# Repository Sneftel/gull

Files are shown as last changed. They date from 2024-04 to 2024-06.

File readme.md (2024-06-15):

# Gull

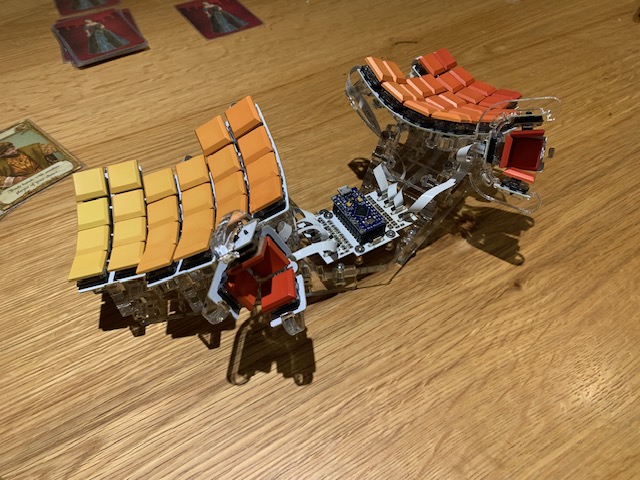
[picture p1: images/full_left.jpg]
Full-frame, three-quarters angle photo of a sweet-ass keyboard


**NOTE:** These images are from Gull V1. V2 is quite similar, but the thumb cluster attaches to the rib rather than being a part of it.

Gull is a dished ergonomic keyboard. It contains no 3D-printed parts and no hand-wired circuitry, and is designed for rapid constructibility rather than aesthetics. Keys are inserted into thin FR4 PCBs which are bent to the frame.

The raison d'etre of Gull is to be rapidly assembled, tweaked, and remade. The frame is fully parameterized, and changing a parameter generally only requires recutting one shape. PCBs can be reused after changing almost any parameters. The exposed ribbon cables make it potentially impractical for portable use.

The key layout is essentially 3x6 on each side. There are six additional keys per side, two in the bottom center of each side and four (relatively inaccessible) keys at the top corners of each side.

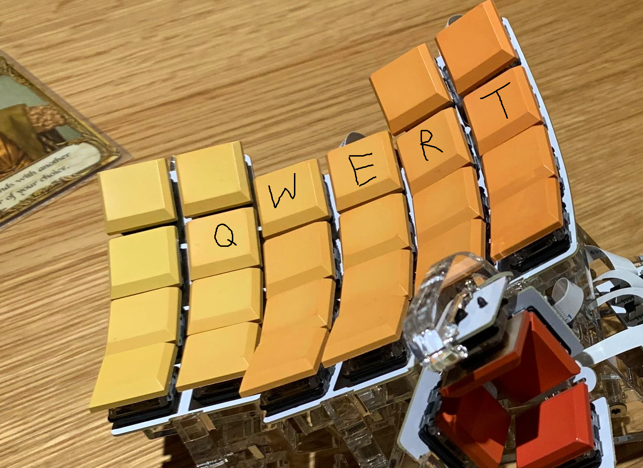
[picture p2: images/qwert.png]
Diagram of the alignment of the QWERTY layout with the key layout


PCB layout is in KiCad. Frame shapes are in OpenSCAD. The firmware is QMK; the fork is available at https://github.com/Sneftel/qmk_firmware/tree/gull , and will be PR'd back when I get some time to clean it up.

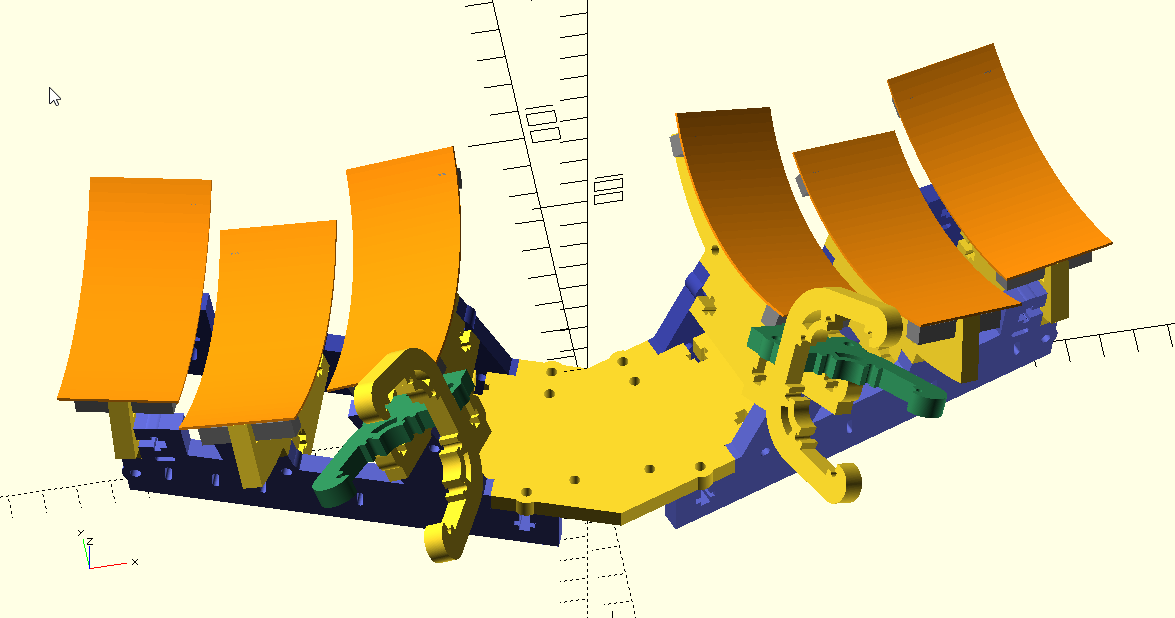
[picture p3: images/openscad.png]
Screenshot of editing the keyboard in OpenSCAD


## Tools

The frame for Gull must be cut from acrylic or similar using a laser cutter.

The PCBs have surface-mount components. A hotplate is the best tool for soldering these, but hand soldering is also possible. Hot air reflow can be used but be aware of temperature limits for the FFC connectors.

Good tweezers are useful for working with the FFC cables, particularly with SOWgull.

## Materials

I use six millimeter-thick acrylic for the frame. Eight millimeter will also work. Below six millimeters is not recommended. Plywood will likely also be acceptable, though I have not tested the most recent shapes with plywood.

The finger and thumb PCBs should be fabricated from 0.8mm-thick FR4. I have not tested other materials or thicknesses. The center PCB should be fabricated from thicker FR4 (I use standard 1.6mm-thick FR4).

## Parts

The following parts are required:

### Hardware 

* 38 14mm-long M3 bolts (not countersunk)
* 26 10mm-long M3 bolts (not countersunk)
* 56 M3 square nuts. I used 6mm width, 2mm thickness, but other sizes will also work.
* 4 4mm female-threaded hex spacers
* 2 20mm female-threaded hex spacers for each bending clamp (optional, discussed below)
* 4 M3 hex nuts

### Components

* 56 Kailh Choc V1 low-profile keyswitches
* 56 Choc V1 keycaps
* 56 0805 diodes
* 16 vertical FFC connectors, 10 pin, 0.5mm pitch. I used GCT FFC2A33 connectors. Other brands will likely work, but check that the land pattern is roughly equivalent. In particular, check that the upper pins are skewed right of the lower pins.
* 8 FFC ribbon cables in various lengths from 10cm to 25cm, 10pin, 0.5mm pitch. I used type B (opposite side contacts) because that gives more flexibility to orient them with the marked side hidden, but type A will also work.
* Pins and sockets for a Pro Micro MCU
* Pro Micro MCU (or pinout-compatible)

### Laser-cut pieces

* 6 ribs, 2 for each position
* 4 spines
* 2 thumb cluster necks
* 2 thumb cluster bodies
* 12 stabilizers
* 1 pelvis
* 2 bending clamps for each distinct rib radius (optional, discussed below)

### PCBs

* 6 fingerboards, in 0.8mm FR4
* 2 thumbboards, in 0.8mm FR4
* 1 centerboard, in 1.6mm FR4 or similar

## Customization

### Basic development

Most customization should be done through frame/params.scad. This file contains almost all parameters one might want to tweak, and documents which pieces are affected by which parameters. 

To visualize the keyboard as a whole, open frame/main.scad. This file should not be used to generate shapes for laser cutting.

### Dilation

The OpenSCAD files dilate some parts to account for the laser cutter's kerf. If your cutter's control software includes this as a feature, you should either disable it in the control software, or disable the dilation by setting the KERF parameter in params.scad to 0. Otherwise, cut a 10mm square, measure the average of its side lengths and subtract that from 10, and set KERF to that value. If the kerf is above 0.6 or so, you may have trouble getting things to fit firmly.

### Customizing the T-slots

For easy assembly, it's useful for the square nuts to firmly friction-fit into the T-slots. This requires a fairly tight tolerance. The "tnuttester.scad" file can be used to empirically determine the right parameters for this, given a particular laser cutter and material. See the comments in that file for how to use it.

### Customizing the bending clamp

If you have customized the rib radii, you will need to customize the bending clamp radius to match (the parameter BEND_RADIUS in clamp.scad), and you will need to fabricate separate clamp shapes for each distinct rib radius. 

## Fabrication

### PCBs

The fingerboards and centerboard may be panelized or printed as-is. To build Gerber files which should be acceptable at most fabs (I use Elecrow), run makeall.bat or "make" in the board directory.

The thumbboard has delicately narrow areas and should be carefully panelized for fabrication. I use KiKit for this, with "panelize.json" containing the necessary presets. The auto-built Gerbers are panelized in this way. Make sure to mention the need for V-cuts to the PCB fabricator. Mousebites would also work.

The center FFC connector on the centerboard, just below the MCU, is for future expansion and does not need to be populated.

### Laser-cut shapes

Execute "make svg" or (on Windows) "makeall.bat svg" to generate SVG shapes for all laser-cut pieces. DXF and PDF outputs are also supported.

I use Deepnest.io to nest the pieces for printing. Consider manually nesting the stabilizers and printing them separately.

The OpenSCAD files dilate some parts to account for laser-cut kerf. See the discussion of kerf in the "customization" section.

## Assembly

Follow the following steps for assembly:

### Solder the PCBs

The thumbboards should remain panelized until after both SM and TH components are soldered. 

Solder only one connector per thumbboard: J1 on one, J2 on the other. The thumb cluster switches will be on the opposite side from the connector.

The FFC connectors have pin 1 indicators that are subtle at best. Make sure to solder them consistently; the connections will work when reversed if the column pin mapping is reversed.

### Assemble the frame

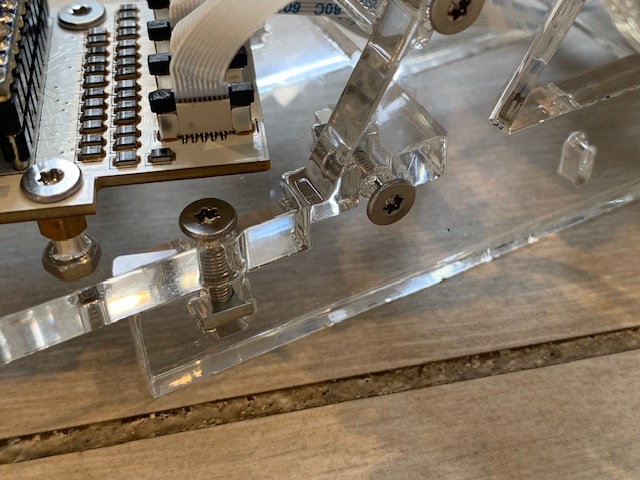
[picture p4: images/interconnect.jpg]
Closeup of the frame interconnects


It's marginally easier to do this before attaching the thumb and finger PCBs. First attach the spines to the pelvis, then the ribs to the spine. (You will use only the 14mm bolts for these.)

Ideally, the square nuts can be press-fit into the T-slots and will stay there for assembly. If a fit is too loose or tight, try a different nut, or try rotating the nut. A drop of glue, or a piece of tape, can also be used to keep things in position.

### Assemble the bending clamp

The shapes include a clamp for use when mounting the fingerboards to the ribs. You can insert each fingerboard into the clamp (keys towards the clamp) and bend and hold it in place with one hand. This makes it easier to bolt it down. 

However, this clamp requires 20mm spacers, which you otherwise wouldn't need, so you can keep your BOM down a bit by bending the fingerboards without one; this option is discussed below.

To assemble the clamp, insert a 10mm bolt in each hole and screw down to a 20mm spacer on the other side. Then put the other clamp on the other side of the spacers and bolt to the spacers with two more 10mm bolts.

### Mount fingerboards

If you have the bending clamp: Insert a fingerboard all the way into the back of the clamp (the FFC connector will be towards the back, and facing the curved surfaces of the clamp), place a stabilizer on the fingerboard (under the hooks at the end) and bend and hold it to the curve with your non-dominant hand.  Use your other hand to insert the bolts and screw them down, inserting a second stabilizer on the other side as you do so. Then tighten everything down and adjust the stabilizers.

If you don't have the bending clamp: It's easiest to mount the fingerboards with two people, one bending the board to the frame and one inserting the 10mm bolts. Failing that, bend in as well as possible and attach the center bolt but do not fully tighten it. Then insert a stabilizer on each side (it will not yet fit firmly). Continue to bend and attach the other two bolts, then tighten everything down and adjust the stabilizers.

### Mount thumbboards

Break off the frames. Fit square nuts into the thumb cluster bodies for later. 

The thumb cluster PCBs should have the connector facing away from the user; swap left and right if this is not the case. Carefully bend the row of three keys to insert into the body of the thumb cluster, with the PCB inserted from the same side as the T-slot is on. Go slow and make sure the PCB is slotting in correctly. The fit should be firm but there should be no need to force anything.

Then attach the necks. Both will slide in from the bottom. Bolt the necks in while checking for centered and square positioning. Then attach the thumb clusters to the rest of the frame.

### Mount centerboard

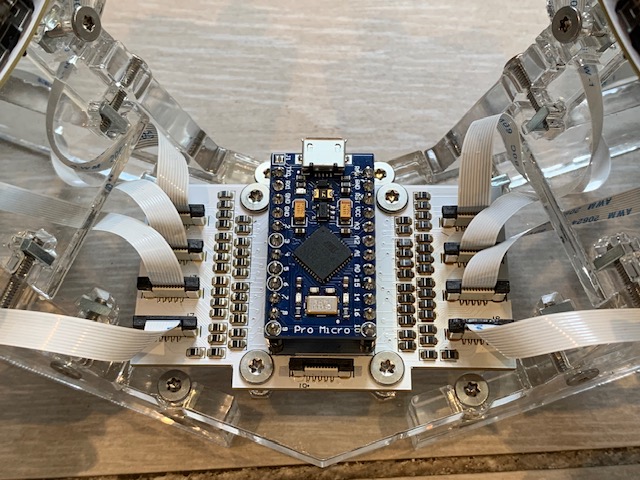
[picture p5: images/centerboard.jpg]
Closeup of the centerboard


Attach four 14mm bolts from the top of the centerboard and secure finger-tight with the 4mm spacers on the bottom. Insert the bolt shanks through the holes in the pelvis and secure with nuts.

### Attach cables and microcontroller.

Insert and secure FFC ribbon cables in the centerboard one by one, fishing them through the frame and inserting them into the fingerboards and thumbbboards. Take care they are oriented properly, and if desired reverse them so the printing is on a consistent side. The thumb cluster cables must be connected to the two side connectors closest to the user. The other cables are intended to be connected with the outermost fingerboards on the connectors further from the user, but row pins can be remapped to compensate if they are connected differently.

Finally, insert the microcontroller. (It's easiest to do this last, so there's more room to connect the cables.)

### Fix row/column mappings

There's a decent chance that the row/column mappings in info.json won't be correct, depending on which FFC cables you used and how you mounted the connectors. If you add 

## SOWGull

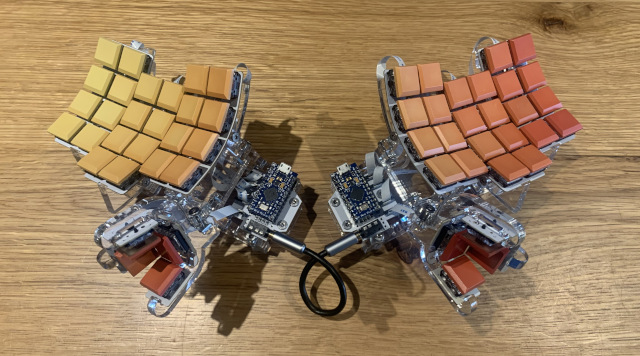
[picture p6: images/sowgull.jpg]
Gull, but split


SOWGull is a split variant of Gull, with a 3.5mm audio cable used to connect the halves.

Most of SOWGull is the same as a normal Gull, and it is easy to convert a Gull into a SOWGull (or vice versa). Only the centerboard and pelvis differ.

### Parts

The BOM has the following differences:

* PCBs: Two SOW boards instead of one centerboard.
* Laser-cut shapes: Two sowpelvis shapes instead of one pelvis shape.
* Hardware: Two additional 10mm-long M3 bolts, two additional 4mm hex spacers, and two additional hex nuts.
* Components: Two PJ-320A 3.5mm TRRS jacks; two Pro Micro boards instead of one; a TRS or TRRS cable for connection.

### Assembly

The SOW board is a reversible PCB. The microcontroller board should be mounted with the USB port facing away from the user, and as far away as possible from the user (with four through-holes towards the user left unused). The TRRS jack is mounted closer to the user.

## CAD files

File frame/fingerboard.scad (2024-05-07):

// Curved fingerboard PCB shape. Used only by main.scad.

include <util.scad>
include <params.scad>
include <pn.scad>

module TopComponent(radius, x, y, width, height, depth)
{
	EXTRA_HEIGHT = sqrt(pow(radius-FINGERBOARD_THICKNESS, 2) - pow(height/2, 2));
	translate([0,radius,x]) RotZ(angleFromLen(radius, y)) translate([0,-EXTRA_HEIGHT+depth/2,0])
        pn_pos() cube([height, depth, width], center=true);
}

module BottomComponent(radius, x, y, width, height, depth)
{
	translate([0,radius,x]) RotZ(angleFromLen(radius, y)) translate([0,-radius-depth/2,0])
        pn_pos() cube([height, depth, width], center=true);
}

module Components(radius)
{
	TopComponent(radius, -10, 30, 14, 14, 6);
	TopComponent(radius, 10, 30, 14, 14, 6);
	TopComponent(radius, -10, 10, 14, 14, 6);
	TopComponent(radius, 10, 10, 14, 14, 6);
	TopComponent(radius, -10, -10, 14, 14, 6);
	TopComponent(radius, 10, -10, 14, 14, 6);
	TopComponent(radius, -10, -30, 14, 14, 6);
	TopComponent(radius, 10, -30, 14, 14, 6);
	BottomComponent(radius, 0, 35, 10, 2, 5);

}

module FingerboardPCB(radius)
{
	EXTRA = 1;

	REAR_ANGLE = angleFromLen(radius, FINGERBOARD_REARWARD_EXTENT);
	FRONT_ANGLE = angleFromLen(radius, FINGERBOARD_FORWARD_EXTENT);

	color("#FF9209")
	linear_extrude(FINGERBOARD_PCB_WIDTH, center=true)
	translate([0,radius,0])
	RotZ(REAR_ANGLE/2-FRONT_ANGLE/2)
		pn_pos() CocktailSausage(minorRadius=radius-FINGERBOARD_THICKNESS, angle=REAR_ANGLE+FRONT_ANGLE, thickness=FINGERBOARD_THICKNESS);
		
	Components(radius);
}

pn_top() FingerboardPCB(80);

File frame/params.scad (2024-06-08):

// IMPORTANT PARAMETERS WHICH YOU MAY WELL WANT TO CUSTOMIZE
//
// These parameters are those you are most likely to want to customize because they relate directly to the positioning of the keys.
// Each parameter in this section is annotated with which parts it affects:
// S: spine
// RA, RB, RC: ribs (centermost to outermost)
// P: pelvis
// T: stabilizers
// N: TC neck
// B: TC body

// The nominal thickness of the sheet material. Parts will still mate and work properly if they vary from this width by up to THICKNESS_TOLERANCE. (S)
THICKNESS = 6; //0.1

// The kerf width of the cutter. Determine this by subtracting the measured width of a cut piece from the nominal width. If your laser cutter software supports kerf correction including clearout of reflex corners, you may want to set this to zero. (ALL)
KERF = 0.3;

// Whether certain inside corners with parts fitting into them should be cleared with dogbone fillets. Disabling this may prevent pieces from fitting together as cleanly, and increase the risk of cracking in T-slots.
CLEAR_INNER_CORNERS = true;

// The position of the join point between the inner ribs and the spine, in the plane of the spine (S)
RIB_A_POS = [-40,45];
// The angle in the plane of the spine by which the inner ribs are rolled away from the center (S)
RIB_A_ANGLE = 30;
// The distance by which the inner ribs are shifted backwards from having their lowest point centered between the spines (RA)
RIB_A_SHIFT = 0;
// The radius described by the fingerboards on the inner ribs (RA)
RIB_A_RADIUS = 80; //5
// The angle by which the fingerboards on the inner ribs are canted away from the user (RA)
RIB_A_PITCH = 10;

// The position of the join point between the second ribs and the spine, in the plane of the spine (S)
RIB_B_POS = [-82,25];
// The angle in the plane of the spine by which the second ribs are rolled away from the center (S)
RIB_B_ANGLE = 20;
// The distance by which the second ribs are shifted backwards from having their lowest point centered between the spines (RB)
RIB_B_SHIFT = 0;
// The radius described by the fingerboards on the second ribs (RB)
RIB_B_RADIUS = 80; //5
// The angle by which the fingerboards on the second ribs are canted away from the user (RB)
RIB_B_PITCH = 0;

// The position of the join point between the outer ribs and the spine, in the plane of the spine (S)
RIB_C_POS = [-125,15];
// The angle in the plane of the spine by which the outer ribs are rolled away from the center (S)
RIB_C_ANGLE = 10;
// The distance by which the outer ribs are shifted backwards from having their lowest point centered between the spines (RC)
RIB_C_SHIFT = 0;
// The radius described by the fingerboards on the outer ribs (RC)
RIB_C_RADIUS = 80; //5
// The angle by which the fingerboards on the outer ribs are canted away from the user (RC)
RIB_C_PITCH = 10;

// The angle by which each half of the keyboard is rotated backwards in the horizontal plane (P)
PELVIS_HALF_ANGLE = 20;

// Extra height added to the stabilizer beyond nominal height. This should be determined experimentally, to produce flat fingerboard ends (T)
STABILIZER_EXTRA_HEIGHT = 0.8;

// The vertical angle of the thumb cluster (RA)
TC_ELEVATION_ANGLE = 5;

// The distance by which the thumb clusters are shifted inwards from the innermost ribs (N)
TC_INWARD_SHIFT = 28;

// The distance by which the thumb clusters are shifted rearwards (towards the user) (N)
TC_REARWARD_SHIFT = 15;

// The distance by which the thumb clusters are shifted downwards-ish (RA)
TC_DOWNWARD_SHIFT = 5;


// PARAMETERS WHICH ARE USED BY MULTIPLE PARTS
//
// These are here because they're used across multiple files, or were at one time. Most of them don't need to be customized.

$fs = 0.1;
$fa = 2;

TC_INTERCONNECT_OFFSET = 5;

// Maximum allowed deviation from the nominal thickness
THICKNESS_TOLERANCE = 1; //0.1

// The distance between the connection step and the middle of the bolt hole or T-slot on either side.
PELVIS_SPINE_INTERCONNECT_OFFSET = 10;

// The distance between the connection step and the middle of the bolt hole or T-slot on either side.
SPINE_RIB_INTERCONNECT_OFFSET = 7;

// The diameter of the bolt holes and minor width of the T-slots
INTERCONNECT_BOLT_DIAMETER = 3.2;

// The length of the bolts to be used in interconnects between sheet parts. If washers are used, this should be reduced by the washer thickness.
INTERCONNECT_BOLT_LENGTH = 14;

// The diameter of a positive area surrounding the interconnect bolt hole
INTERCONNECT_WASHER_DIAMETER = 8;

// The extra depth below the nut area of T-slots. This should be at least the maximum variance of the actual sheet material thickness below the nominal thickness, plus the maximum variance of the bolt length above the nominal length.
T_SLOT_EXTRA_DEPTH = 0.5;

// The width of the T-slot; this should be the width of your nuts
$T_SLOT_NUT_WIDTH = 6.2; //0.1

// The depth of the nut area of the T-slot; this should be the thickness of your nuts
$T_SLOT_NUT_DEPTH = 2; //0.1

// The offset of the nut area above the end of the screw in the T-slot. This should be at least the taper length
T_SLOT_NUT_OFFSET = 1.5; //0.1

// The radius of the circular "bumpers" at the opening of the T-slot
T_SLOT_BUMPER_RADIUS = 0.25;

// The distance between the outer extents of the front and back legs
SPINES_OUTER_SPACING = 50;

// The distance between the pelvis's rear center angle and its outer edges, measured along the spine angles
PELVIS_REAR_HALF_WIDTH = 40; //5

// The height of the bottom bar of the spine
SPINE_BASE_HEIGHT = 20;

// The length of the capsule-shaped cable guide cutouts. Should be greater than the width of the FFC ribbons.
CABLE_GUIDE_LENGTH = 6;

// The width of the capsule-shaped cable guide cutouts. Should be wide enough to make inserting the FFC ribbons easy.
CABLE_GUIDE_WIDTH = 2;

// The height of the stabilizers.
STABILIZER_HEIGHT = 8;

// The major width of the stabilizers, which must sit between the outer mounting posts of the keyswitches.
STABILIZER_OUTER_WIDTH = 29;

// The minor with of the stabilizers, which must sit outside the center posts of the keyswitches.
STABILIZER_INNER_WIDTH = 24;

// The vertical clearance of the middle of the stabilizers below the fingerboards. 
STABILIZER_VERTICAL_INSET = 2.5;

// The length of the fingerboard forward of the center of the middle bolt hole
FINGERBOARD_FORWARD_EXTENT = 38;

// The length of the fingerboard rearward of the center of the middle bolt hole
FINGERBOARD_REARWARD_EXTENT = 38;

// The thickness of the fingerboard PCBs. This probably doesn't need to be changed even if a different PCB is used, as long as it's no more than 1.2 or so.
FINGERBOARD_THICKNESS = 0.8;

// The diameter of the bolt holes and minor width of the T-slots used to connect the fingerboard PCBs.
FINGERBOARD_BOLT_DIAMETER = 3;

// The nominal length of the bolts used to connect the fingerboard PCBs.
FINGERBOARD_BOLT_LENGTH = 10;

// The width of the fingerboard PCBs (this is used only for preview rendering).
FINGERBOARD_PCB_WIDTH = 36;

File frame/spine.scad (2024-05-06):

// The forward-backward-perpendicular-ish shapes which extend out from the pelvis and support the ribs.

include <util.scad>
include <params.scad>
include <pn.scad>

SPINE_RISER_WIDTH = 20;
SPINE_LENGTH = -RIB_C_POS.x;
CABLE_TRUNK_HEIGHT = 10;

function trunkX(pos, angle, offset) = pos.x + (pos.y - CABLE_TRUNK_HEIGHT)*tan(angle) + offset;

module SpineBase()
{
    LARGE = 1000;

    pn_pos() Rect(SPINE_LENGTH, SPINE_BASE_HEIGHT, ANCHOR_RB);

    translate([0,SPINE_BASE_HEIGHT]) RotZ(180) {
        Interconnect("foo", PELVIS_SPINE_INTERCONNECT_OFFSET) children();
    }
}

module SpineRiser(name)
{
    LARGE = 1000;
    
    translate([THICKNESS/2, 0])
        pn_pos() Rect(SPINE_RISER_WIDTH, LARGE, ANCHOR_RT, extraY=2*SPINE_RIB_INTERCONNECT_OFFSET);

    translate([-SPINE_RISER_WIDTH/2,0]) RotZ(90)
        CableGuide();

    translate([THICKNESS/2,2*SPINE_RIB_INTERCONNECT_OFFSET]) scale([-1,1,1]) RotZ(-90)
        Interconnect(name, SPINE_RIB_INTERCONNECT_OFFSET) children();
}

module SpineRisers()
{
    LARGE = 1000;

    translate(RIB_A_POS) RotZ(RIB_A_ANGLE) SpineRiser("riserA") children();
    translate(RIB_B_POS) RotZ(RIB_B_ANGLE) SpineRiser("riserB") children();
    translate(RIB_C_POS) RotZ(RIB_C_ANGLE) scale([-1, 1,1]) SpineRiser("riserC") children();

    pn_neg() Rect(LARGE, LARGE, ANCHOR_CT);
}

module SpineTrunks()
{
    TRUNK_X_A = trunkX(RIB_A_POS, RIB_A_ANGLE, -SPINE_RISER_WIDTH/2);
    TRUNK_X_B = trunkX(RIB_B_POS, RIB_B_ANGLE, -SPINE_RISER_WIDTH/2);
    TRUNK_X_C = trunkX(RIB_C_POS, RIB_C_ANGLE, SPINE_RISER_WIDTH/2);

    translate([(TRUNK_X_A+TRUNK_X_B)/2, CABLE_TRUNK_HEIGHT])
        CableGuide();
    translate([TRUNK_X_B, CABLE_TRUNK_HEIGHT])
        CableGuide();
    translate([(TRUNK_X_B+TRUNK_X_C)/2, CABLE_TRUNK_HEIGHT])
        CableGuide();
    translate([TRUNK_X_C, CABLE_TRUNK_HEIGHT])
        CableGuide();
}

module Spine()
{
    SpineBase() children();
    SpineRisers() children();
    SpineTrunks() children();
}

module Spine_Anchored()
{
    translate([2*PELVIS_SPINE_INTERCONNECT_OFFSET, -SPINE_BASE_HEIGHT+THICKNESS/2])
        Spine() children();
}

Dekerf() pn_top() Spine_Anchored();

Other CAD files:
frame/clamp.scad
frame/main.scad
frame/pelvis.scad
frame/pn.scad
frame/rib.scad
frame/rib_a.scad
frame/rib_b.scad
frame/rib_c.scad
frame/sowpelvis.scad
frame/stabilizer.scad
frame/tcbody.scad
frame/tccommon.scad
frame/tcmain.scad
frame/tcneck.scad
frame/tnuttester.scad
frame/util.scad

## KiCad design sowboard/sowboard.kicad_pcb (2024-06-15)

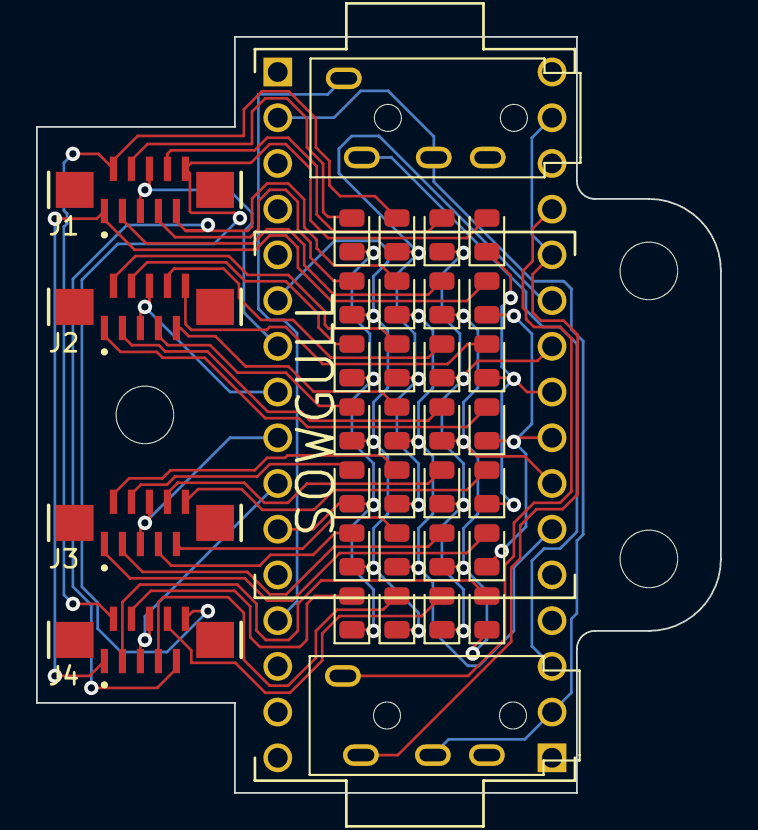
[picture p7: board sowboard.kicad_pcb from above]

Board: 2 copper layers, 38.0 x 42.0 mm, 35 parts (0 on the bottom side), 45 nets.

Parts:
D1, D2, D3, D4, D5, D6, D7, D8, D9, D10, D11, D12, D13, D14, D15, D16, D17, D18, D19, D20, D21, D22, D23, D24, D59, D60, D61, D62: 1N4148W; D_0805_2012Metric
J1, J2, J3, J4: Conn_01x10_MountingPin; GCT_FFC2A33-10-T-R_REVA
U1: ProMicro; ProMicro-Rotatable
U2, U3: PJ-320A

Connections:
/Column L1/R1: D1.2 (A), J1.1, J4.1
/Column L1/R2: D2.2 (A), J1.2, J4.2
/Column L1/R7: D7.2 (A), J1.9, J4.9
/Column L1/R8: D8.2 (A), J1.10, J4.10
/Column L2/R1: D9.2 (A), J2.1
/Column L2/R2: D10.2 (A), J2.2
/Column L2/R7: D15.2 (A), J2.9
/Column L2/R8: D16.2 (A), J2.10
/Column L3/R1: D17.2 (A), J3.1
/Column L3/R2: D18.2 (A), J3.2
/Column L3/R7: D23.2 (A), J3.9
/Column L3/R8: D24.2 (A), J3.10
COL_L1: J1.5, J1.6, U1.7 (D4)
COL_L2: J2.5, J2.6, U1.8 (C6)
COL_L3: J3.5, J3.6, U1.9 (D7)
COL_T: J4.5, J4.6, U1.10 (E6)
unnamed: D3.2 (A), J1.3
unnamed: D4.2 (A), J1.4
unnamed: D5.2 (A), J1.7
unnamed: D6.2 (A), J1.8
unnamed: D11.2 (A), J2.3
unnamed: D12.2 (A), J2.4
unnamed: D13.2 (A), J2.7
unnamed: D14.2 (A), J2.8
unnamed: D19.2 (A), J3.3
unnamed: D20.2 (A), J3.4
unnamed: D21.2 (A), J3.7
unnamed: D22.2 (A), J3.8
unnamed: D59.2 (A), J4.3
unnamed: D60.2 (A), J4.4
unnamed: D61.2 (A), J4.7
unnamed: D62.2 (A), J4.8
unnamed: U1.20 (F4), U1.23 (GND), U3.2 (Tip)
unnamed: U1.2 (RX), U1.2B (RX), U2.3 (Ring1), U3.3 (Ring1)
unnamed: U1.21B (VCC), U2.1 (Sleeve)
unnamed: U1.3B (GND), U2.2 (Tip)
unnamed: U1.21 (VCC), U3.1 (Sleeve)
ROW_1: D1.1 (K), D9.1 (K), D17.1 (K), U1.16 (B1)
ROW_2: D2.1 (K), D10.1 (K), D18.1 (K), U1.19 (F5)
ROW_3: D3.1 (K), D11.1 (K), D19.1 (K), D59.1 (K), U1.15 (B3)
ROW_4: D4.1 (K), D12.1 (K), D20.1 (K), D60.1 (K), U1.11 (B4)
ROW_5: D5.1 (K), D13.1 (K), D21.1 (K), D61.1 (K), U1.6 (SCL)
ROW_6: D6.1 (K), D14.1 (K), D22.1 (K), D62.1 (K), U1.18 (F6)
ROW_7: D7.1 (K), D15.1 (K), D23.1 (K), U1.14 (B2)
ROW_8: D8.1 (K), D16.1 (K), D24.1 (K), U1.17 (F7)

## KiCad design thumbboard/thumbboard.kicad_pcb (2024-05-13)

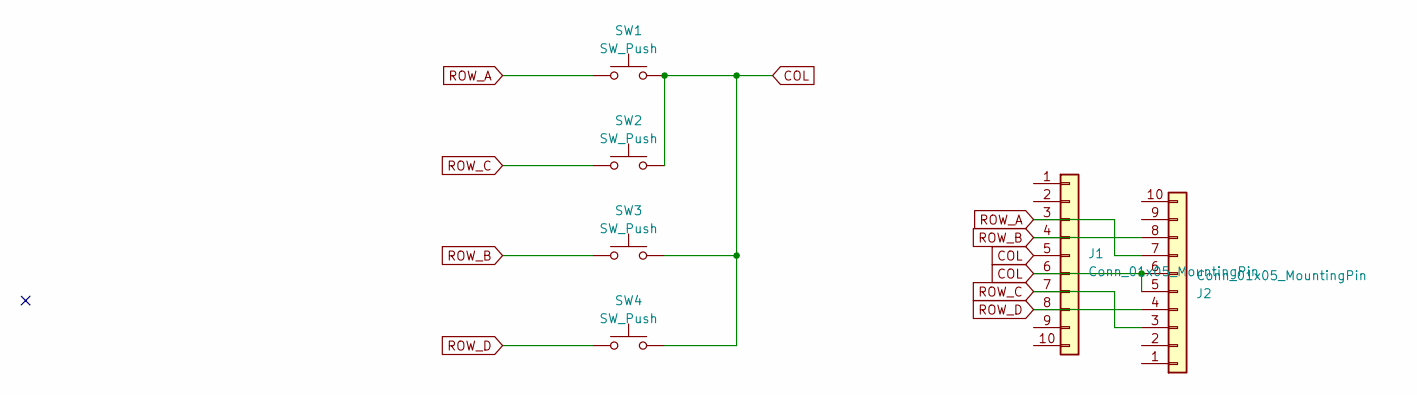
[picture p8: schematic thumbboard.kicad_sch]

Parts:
J1: Conn_01x05_MountingPin; GCT_FFC2A33-10-T-R_REVA_Clipped1
J2: Conn_01x05_MountingPin; GCT_FFC2A33-10-T-R_REVA_Clipped2
SW1, SW3, SW4: SW_Push; SW_PG1350_reversible
SW2: SW_Push; SW_PG1350_reversible_MissingCorner

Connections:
COL: J1.5, J1.6, J2.5, J2.6, SW1.1, SW2.1, SW3.1, SW4.2
ROW_A: J1.3, J2.7, SW1.2
ROW_B: J1.4, J2.8, SW3.2
ROW_C: J1.7, J2.3, SW2.2
ROW_D: J1.8, J2.4, SW4.1

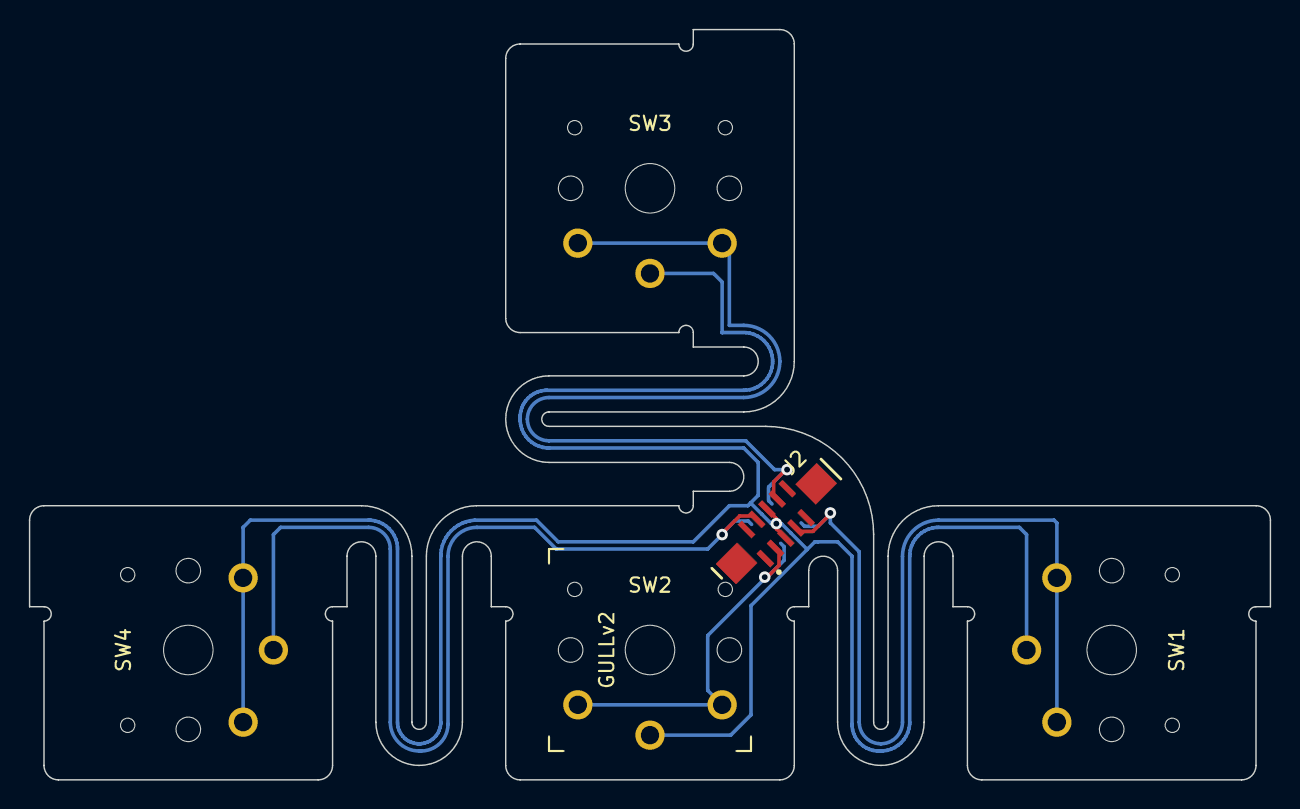
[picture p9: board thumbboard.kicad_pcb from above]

Board: 2 copper layers, 86.0 x 52.0 mm, 12 parts (1 on the bottom side), 5 nets.

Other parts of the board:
T1, T2, T3, T4, T4#2, T4#3: Tab

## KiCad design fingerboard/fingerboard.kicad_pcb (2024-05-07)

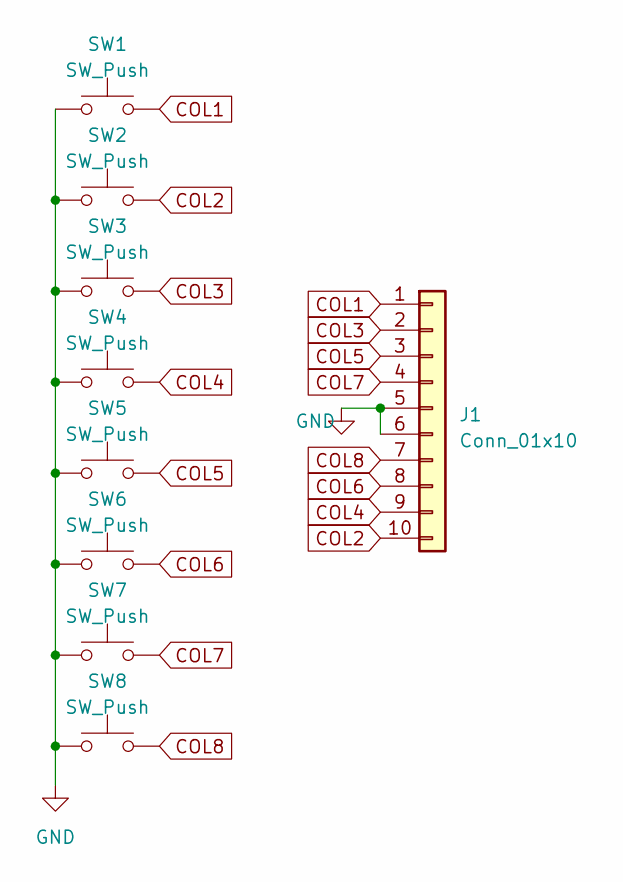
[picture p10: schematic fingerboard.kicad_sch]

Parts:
J1: Conn_01x10; TE_1-1734839-0_1x10-1MP_P0.5mm_Horizontal
SW1, SW2, SW3, SW4, SW5, SW6, SW7, SW8: SW_Push; SW_PG1350

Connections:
COL1: J1.1, SW1.2
COL2: J1.10, SW2.1
COL3: J1.2, SW3.2
COL4: J1.9, SW4.1
COL5: J1.3, SW5.2
COL6: J1.8, SW6.1
COL7: J1.4, SW7.2
COL8: J1.7, SW8.1
GND: J1.5, J1.6, SW1.1, SW2.2, SW3.1, SW4.2, SW5.1, SW6.2, SW7.1, SW8.2

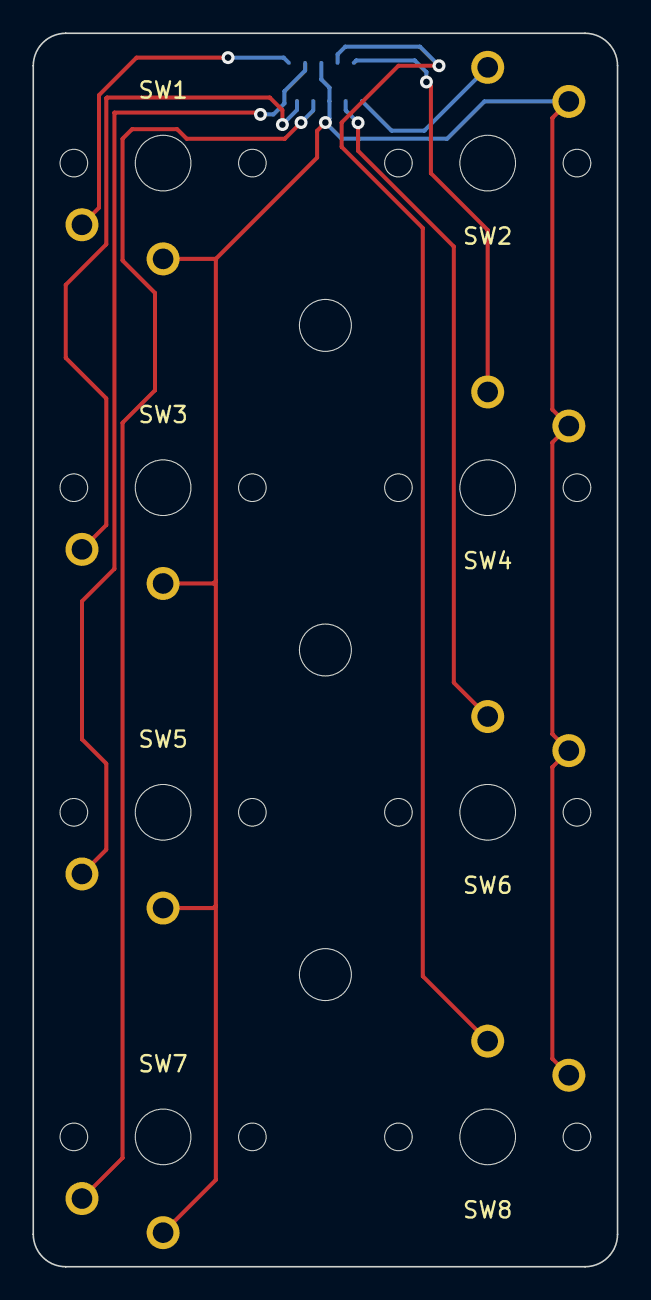
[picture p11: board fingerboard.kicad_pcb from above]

Board: 2 copper layers, 36.0 x 76.0 mm, 9 parts (1 on the bottom side), 9 nets.

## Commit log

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2023-12-13 tweaks and variable renames
    [rib.scad]
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2023-12-14 rename "paddle" to "pcb" when referring to tc pcb rather to than the individual paddles
    [tcbody.scad, tccommon.scad, tcneck.scad]
2023-12-16 Fix loc of rib foot
    [rib.scad]
2023-12-16 Allow actual thickness to diverge from nominal in rendering
    [main.scad]
2023-12-16 Add cable guides; render ribs in main through instantiations to reduce codedup
    [main.scad, params.scad, rib.scad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]
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2024-01-07 Add PN; use it in pelvis
    [pelvis.scad, pn.scad]
2024-01-07 A hack to adjust material thickness without adjusting the PCB (which was designed for 8mm in thumb cluster)
    [tcneck.scad]
2024-01-07 Reduce magic numbers in TC
    [tccommon.scad]
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2024-01-13 Major refactor: Add anchor capabilities to PN; use PN for remaining parts; refactor main to use anchors to position things
    [main.scad, params.scad, pelvis.scad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]
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2024-01-15 Various refactorings. Add fingerboard pcb visualization to main.
    [fingerboard.scad, main.scad, params.scad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]
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2024-01-15 finish refactoring TC to use PN (still needs some cleanup)
    [tcbody.scad, tccommon.scad, tcmain.scad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]
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2024-01-15 mild refactoring of tcbody
    [tcbody.scad]
2024-01-22 redo centerboard again (and again)
    [centerboard.kicad_pcb, centerboard.kicad_sch]
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2024-01-27 Fix Rect impl, add support for EXTRA in Rect
    [util.scad]
2024-01-27 Change naming, misc tweaks, add connector cutout back
    [fingerboard.scad, params.scad, rib.scad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]
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2024-02-01 Add label to thumbboard; make bottom tabs narrower (hard to break off the frame without damaging the thing)
    [thumbboard.kicad_pcb]
2024-02-01 Overhaul T-slots a bit and make them (and the bolts) longer
    [params.scad, stabilizer.scad, util.scad]
2024-02-01 add testing tool to find ideal T-nut thickness
    [tnuttester.scad]
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2024-02-02 Improve the tnuttester to find both width and depth
    [params.scad, tnuttester.scad, util.scad]
2024-02-03 Tidy up tccommon with Rect; add space in ends of TC PCB guides to improve cutting and ease depanelling; slightly thicken TC features which were deforming and breaking
    [tccommon.scad]
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2024-02-03 fix swapped front/back centerboard hole widths (oops)
    [pelvis.scad]
2024-02-03 overhaul TC PCB guide rails again a bit
    [tccommon.scad]
2024-02-03 widen cable guide slots to help clear offcuts
    [params.scad]
2024-02-03 Add corner cutouts to interconnects, so pieces sit flat instead of fulcruming at the shared corner
    [params.scad, util.scad]
2024-02-03 Swap x/y in Rect anchor names
    [pelvis.scad, rib.scad, spine.scad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]
2024-02-03 Add "washer" rings around interconnect bolt holes for more even support
    [params.scad, util.scad]
2024-02-03 Add kerf correction (not sure if this is a good idea)
    [params.scad, pelvis.scad, rib.scad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]
2024-02-03 give the thumb boards just a little bit more room
    [tccommon.scad]
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2024-02-07 Testing and tweaking; added channels to tnuttester to get the test holes closer to the real holes
    [params.scad, tnuttester.scad]
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2024-02-08 Fix T-slot lengths
    [spine.scad]
2024-02-08 Applying results from destructive testing: Make pelvis/spine and spine/rib interconnect lengths independent; lengthen the former; make pelvis wider to make room, move ribs in to compensate
    [params.scad, pelvis.scad, rib.scad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]
2024-02-08 shorten fingerboard bolts
    [params.scad]
2024-02-08 Fix positioning in main.scad when actual thickness varies from nominal thickness
    [main.scad]
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2024-02-14 Flip riser for outer ribs to ease assembly
    [spine.scad]
2024-02-14 Add cable guides in ribs to keep cables closer to the frame
    [rib.scad]
2024-02-14 Remove cable guide from outer rib support (no longer needed now that spine's guide is on the other side)
    [rib_c.scad]
2024-03-24 Rework centerboard yet again. Now with vertical FFC headers and a ground pour.
    [centerboard.kicad_pcb, centerboard.kicad_sch, column.kicad_sch]
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2024-03-24 fix cable guide dimension calculation
    [util.scad]
2024-03-24 shorten cable guides a bit (still longer than before the previous fix); lengthen fingerboard bolts to 10mm
    [params.scad]
2024-03-26 add a bit of extra height to stabilizers (should probably do this with dilation)
    [stabilizer.scad]
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2024-04-28 First V2 work: Add a separate TC body piece, attached to the neck which is in turn attached to the rib. Also add positive geometry around interconnects (to help with debugging placement, mostly)
    [main.scad, params.scad, rib.scad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]
2024-04-28 Tweaks and cleanups. Still need to clean some stuff up and pull out/organize/rename params, and probably remove old params
    [main.scad, params.scad, rib.scad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]
2024-04-28 Add some redundant traces to centerboard to fix benign DRC violations
    [centerboard.kicad_pcb]
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2024-04-29 Swap TC body orientation (still haven't decided which is better)
    [main.scad]
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2024-04-29 Some more TC measurement tweaks and cleanups (still needs work).
    [tcbody.scad, tcneck.scad]
2024-04-29 remove forward rib edge to make room for vertical connector. Still some naked constants to pull out.
    [rib.scad]
2024-04-29 Add tcbody to makefile/makeall.bat. Overhaul makefile a little for deps and readability. Also remove spurious dep of rib on tccommon, and update gitignore.
    [rib.scad]
2024-04-29 Flip the rib-TC attachment to allow for lower TCs
    [main.scad, rib.scad]
2024-04-29 More TC work: cleanups, swapping interconnect directions again, pulling out and documenting parameters. Also getting rid of dead code.
    [main.scad, params.scad, rib.scad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]
2024-04-29 Add positive support region around the nut in T-slots (in all parts, but only relevant to the TC for now)
    [util.scad]
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2024-05-06 overhaul a few things for readability; add pn_pospos() to preserve bumpers in all T-slots
    [fingerboard.scad, params.scad, pelvis.scad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]
2024-05-06 add clamp tool for use when bending fingerboards
    [clamp.scad]
2024-05-06 add non-slipping contact to endhook
    [clamp.scad]
2024-05-06 Add clearance below the keywell underneath the endhook in the clamp, to make it possible to actually wedge the thing in there. Also move that bolt hole to the top of the endhook, for greater stabilit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
    [clamp.scad]
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2024-05-06 prevent fingerboard from catching on clamp undercut
    [clamp.scad]
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2024-05-07 Center fingerboard connector (fraction of a millimeter, not really a practical difference) and put grid origin somewhere useful
    [fingerboard.kicad_pcb]
2024-05-07 Shorten rib leading edge slightly to make more room for FFC
    [rib.scad]
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2024-05-10 Overhaul clamp a bit to grip both the fingerboard and one of its stabilizers
    [clamp.scad]
2024-05-11 Fix undercut positioning; increase overhang
    [clamp.scad]
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2024-05-13 Move silkscreen text to be less noticeable in final kb
    [thumbboard.kicad_pcb]
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2024-06-08 Make bending clamp a little easier to fit fingerboards into, and thin it out to make it easier to bolt down the fingerboards
    [clamp.scad]
2024-06-08 Move TCs inwards to improve keycap clearance
    [params.scad]
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2024-06-08 improve TC/stabilizer clearance so the stabilizer sits more perpendicular
    [rib.scad]
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2024-06-08 Make the clamp look nicer. The *clamp*. Vanity, thy name is Ben.
    [clamp.scad]
2024-06-09 Increase clearance for audio plug
    [sowboard.kicad_pcb]
2024-06-15 Improve sowboard layout a bit, switch the data pin to PD2, and work around DRC warnings
    [column.kicad_sch, sowboard.kicad_pcb, sowboard.kicad_sch]
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
